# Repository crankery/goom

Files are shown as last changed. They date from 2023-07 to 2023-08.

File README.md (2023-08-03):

# Goom VCF

Goom is yet another Moog style transistor ladder VCF for Eurorack. It's setup to be a fairly shallow 14hp module.

This is mainly a re-layout of [Yves Usson's](http://yusynth.net/) [YuSynth MiniMoog VCF](http://yusynth.net/Modular/index_en.html). A few substitions of really super obsolete componetns with only somewhat obsolete components were made. Everything is through-hole mount, I haven't made the leap to SMT yet. There's similar designs using SMT devices out there; just search for "minimoog transistor ladder filter eurorack".

The original design was for a 5U modular synth because that's what Yves was building. You can still [buy the YuSynth PCB](https://www.soundtronics.co.uk/yusynth-diy-synth/) and adapt it to Eurorack power and figure out how to attach it to a front panel but it's really designed to be a MOTM module. 

This used three matched pairs of [BC547C NPN transistors](Documents/BC547.pdf), a [BC557C PNP transistor](Documents/BC557.pdf), a [TL072 op-amp](Documents/tl072h.pdf) and two [CA3046N transistor arrays](Documents/CA3046N.pdf). Of these components, the CA3056 and TL072 are still readily available. There's a clear substition for the transistors as well as a possible better option. The original design was for $\pm15V$; Yves suggests some resistor value changes for Eurorack's $\pm12V$ power. Matching transistors is still possible in this day and age but I felt like it was a pain so I decided to try out another option.

## Changes from YuSynth Design

You can still easily obtain BC5x7 transistors but I happened to have a bunch of 2N3904 and 2N3906 transistors on hand so I elected to use those. Then I decided trying to match pairs of them was a pain. Knowing the [Alfa RPAR AS394](https://www.alfarzpp.lv/eng/sc/AS394CH.pdf) matched transistor pair IC was available, I decided to try that out.
I've left the discrete transistor pads on the PCB.

The 2N3904 is standing in for the BC557, 2N3096 for the BC547N transistors.

Since the AS394 has internal diodes coming off the emitters, I've included pads for 2N4148 diodes on the optional discrete transistor pads. Again, 2N2148 was selected because I had them on hand.

## Design Constraints

The PCB is 100mm in the long dimension which makes it pretty darned cheap to order from [PCBWay](https://www.pcbway.com/). It is 70.8mm wide which [Doepfer says is 14hp](https://doepfer.de/a100_man/a100m_e.htm).

I elected to exclusively use through-hole components and PCB mount vertical potentiometers and jacks. Because some of these components are taller than the jacks and pots most of the components are on the opposite side of the PCB from the components that protrude from the front panel.

The potentiometers used are Alpha RD901F style 9mm vertical PCB mount with 6.35mm (1/4") round shafts and threaded collar to attach the front panel. The 10KΩ anti-log taper potentiometer was not available in this style so I used the RD901F which has a 6mm 18 tooth plastic shaft for resonance/emphasis. The jacks are PJ301BM 3.5mm switched tip mono jacks.

## Parts Sourcing

Most of the hardware and the discrete components were obtained from [Tayda](https://www.taydaelectronics.com/). The AS3046 & AS394 ICs are from [Cabintech](https://cabintechglobal.com/). The TL072 ICs were from either Mouser or Digi-key.

# Design

I started out by re-drawing the original design in [KiCad](https://www.kicad.org).

YuSynth Schematic

## To Do

- [ ] A note on the schematic `** resistor valus to be adjusted to adapt to input and output levels` which applies to R5 and R32. Not sure what the appropriate values are for Eurorack levels and this isn't discussed anywhere on the page
- [ ] The references are different in the KiCad schematic vs the original. Make them match
- [ ] The BOM says `47nF matched to 1%` for C4-7, not sure how to go about that

## Changes From Original

- R24, R27, R26 value changed for $\pm12V$
- Eliminated the MOTM power connection and switched all the $\pm15V$ to $\pm12V$
- Added a Eurorack 10 pin header power connector
- Switched the 3 x 100KΩ resistors to a 4 pin resistor network
- Switched the 4 x 470Ω resistors to an 8 pin isolated resistor pack 
- Added diodes off the matched transitor emitters as per the AS394's internals
- Added optional AS394 ICs to replace the matched transistors

# Front Panel

I'm trying to put the edge cuts for the panel, including jack and pot holes on a user layer. The graphics for the front panel are on another one.

## To Do

- [ ] determine how one goes about exporting a document to send to a service to get panels cut and drilled
- [ ] in the meantime, determine how to export the panel edge cuts layer to a pdf so the holes can be accurately drilled by hand in a blank panel
- [ ] determine how to go about exporting the graphics layer and doing some sort of acid etching process or something

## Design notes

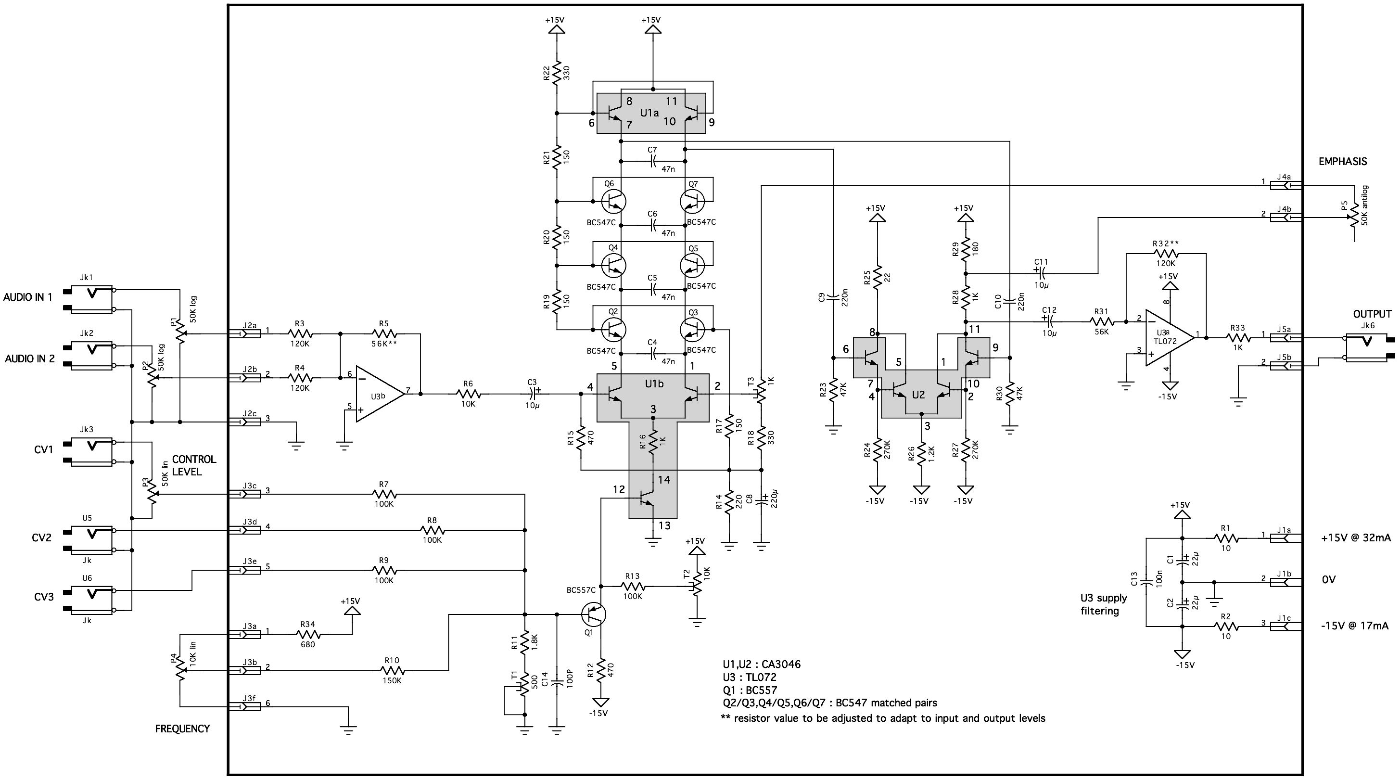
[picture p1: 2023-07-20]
Documents/Moogfilter-sch.jpg

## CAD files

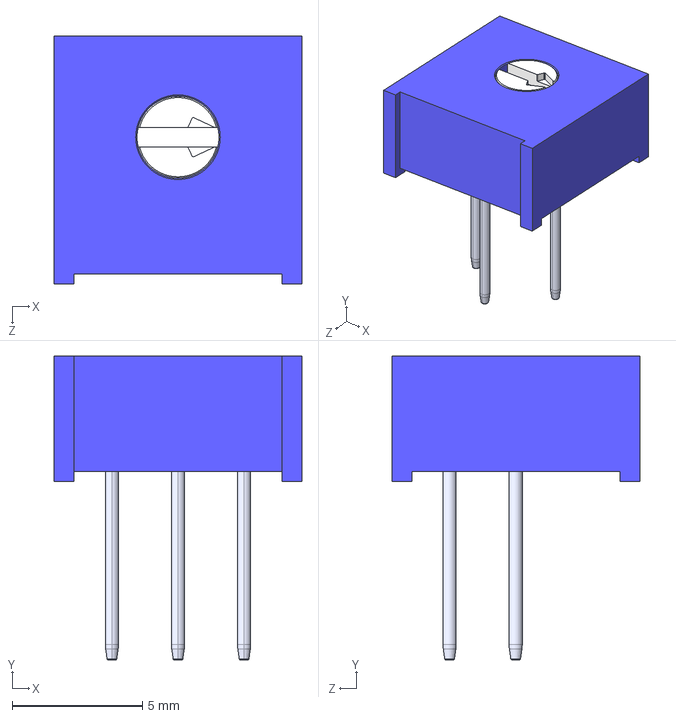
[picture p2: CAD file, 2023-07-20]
3dshapes/3386P-1-502LF.step
9.53 x 11.7 x 9.53 mm

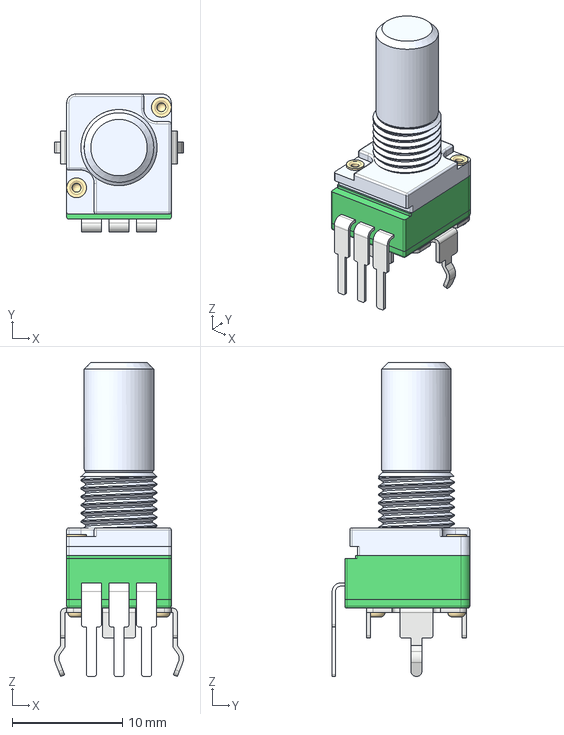
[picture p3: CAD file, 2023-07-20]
3dshapes/RD901F-40-15R1.stp
11.7 x 12.5 x 28.5 mm

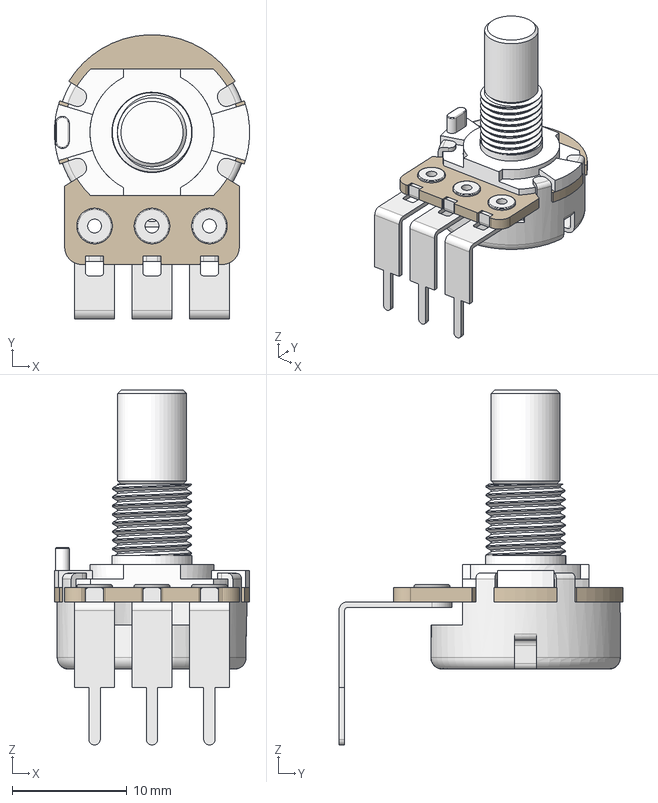
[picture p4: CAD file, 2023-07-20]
3dshapes/RV16AF-41.step
17.0 x 24.7 x 30.9 mm

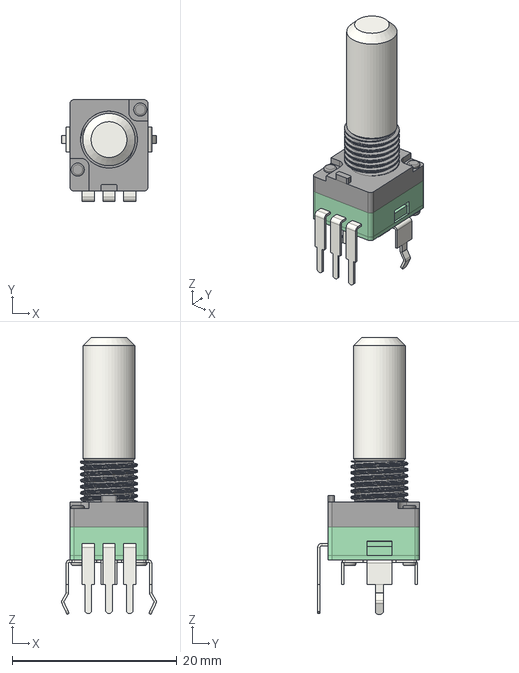
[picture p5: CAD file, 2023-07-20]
3dshapes/ALPHA-RD901F-40.step
11.5 x 12.4 x 33.6 mm

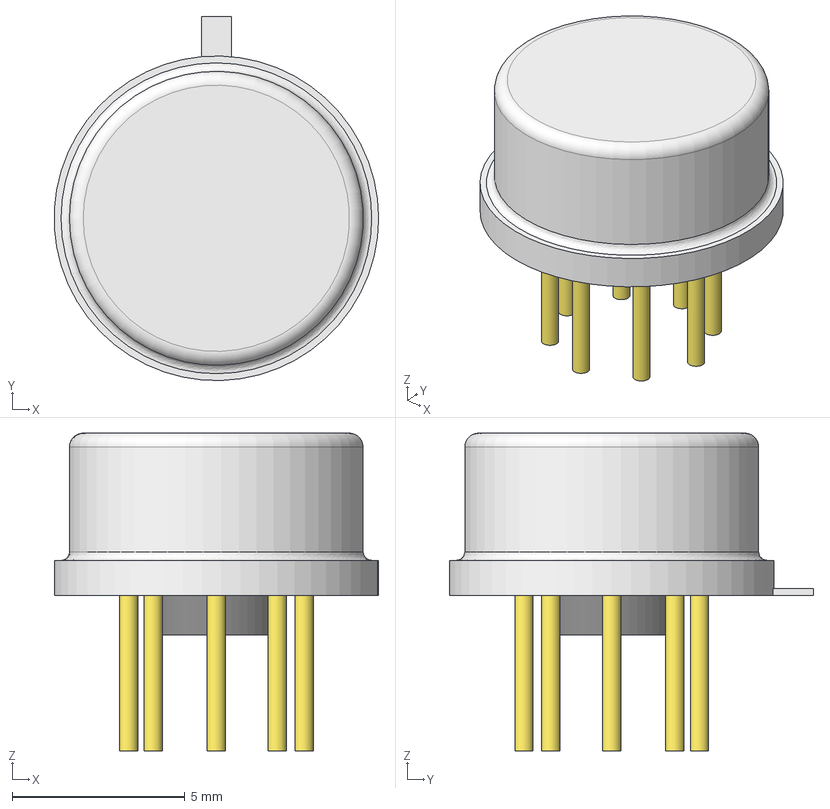
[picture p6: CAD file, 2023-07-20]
3dshapes/TO-5-8pins.step
9.39 x 10.5 x 9.20 mm
Sketch001

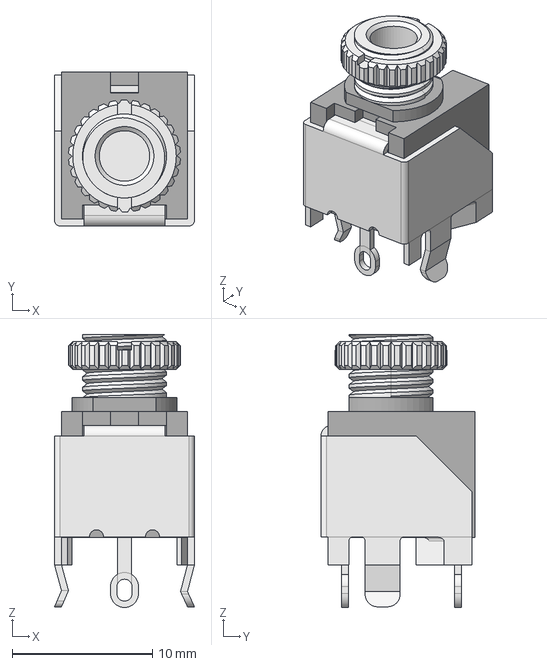
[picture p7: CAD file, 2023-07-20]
3dshapes/PJ301BM_Knurl_nut.step
10.0 x 11.0 x 19.5 mm

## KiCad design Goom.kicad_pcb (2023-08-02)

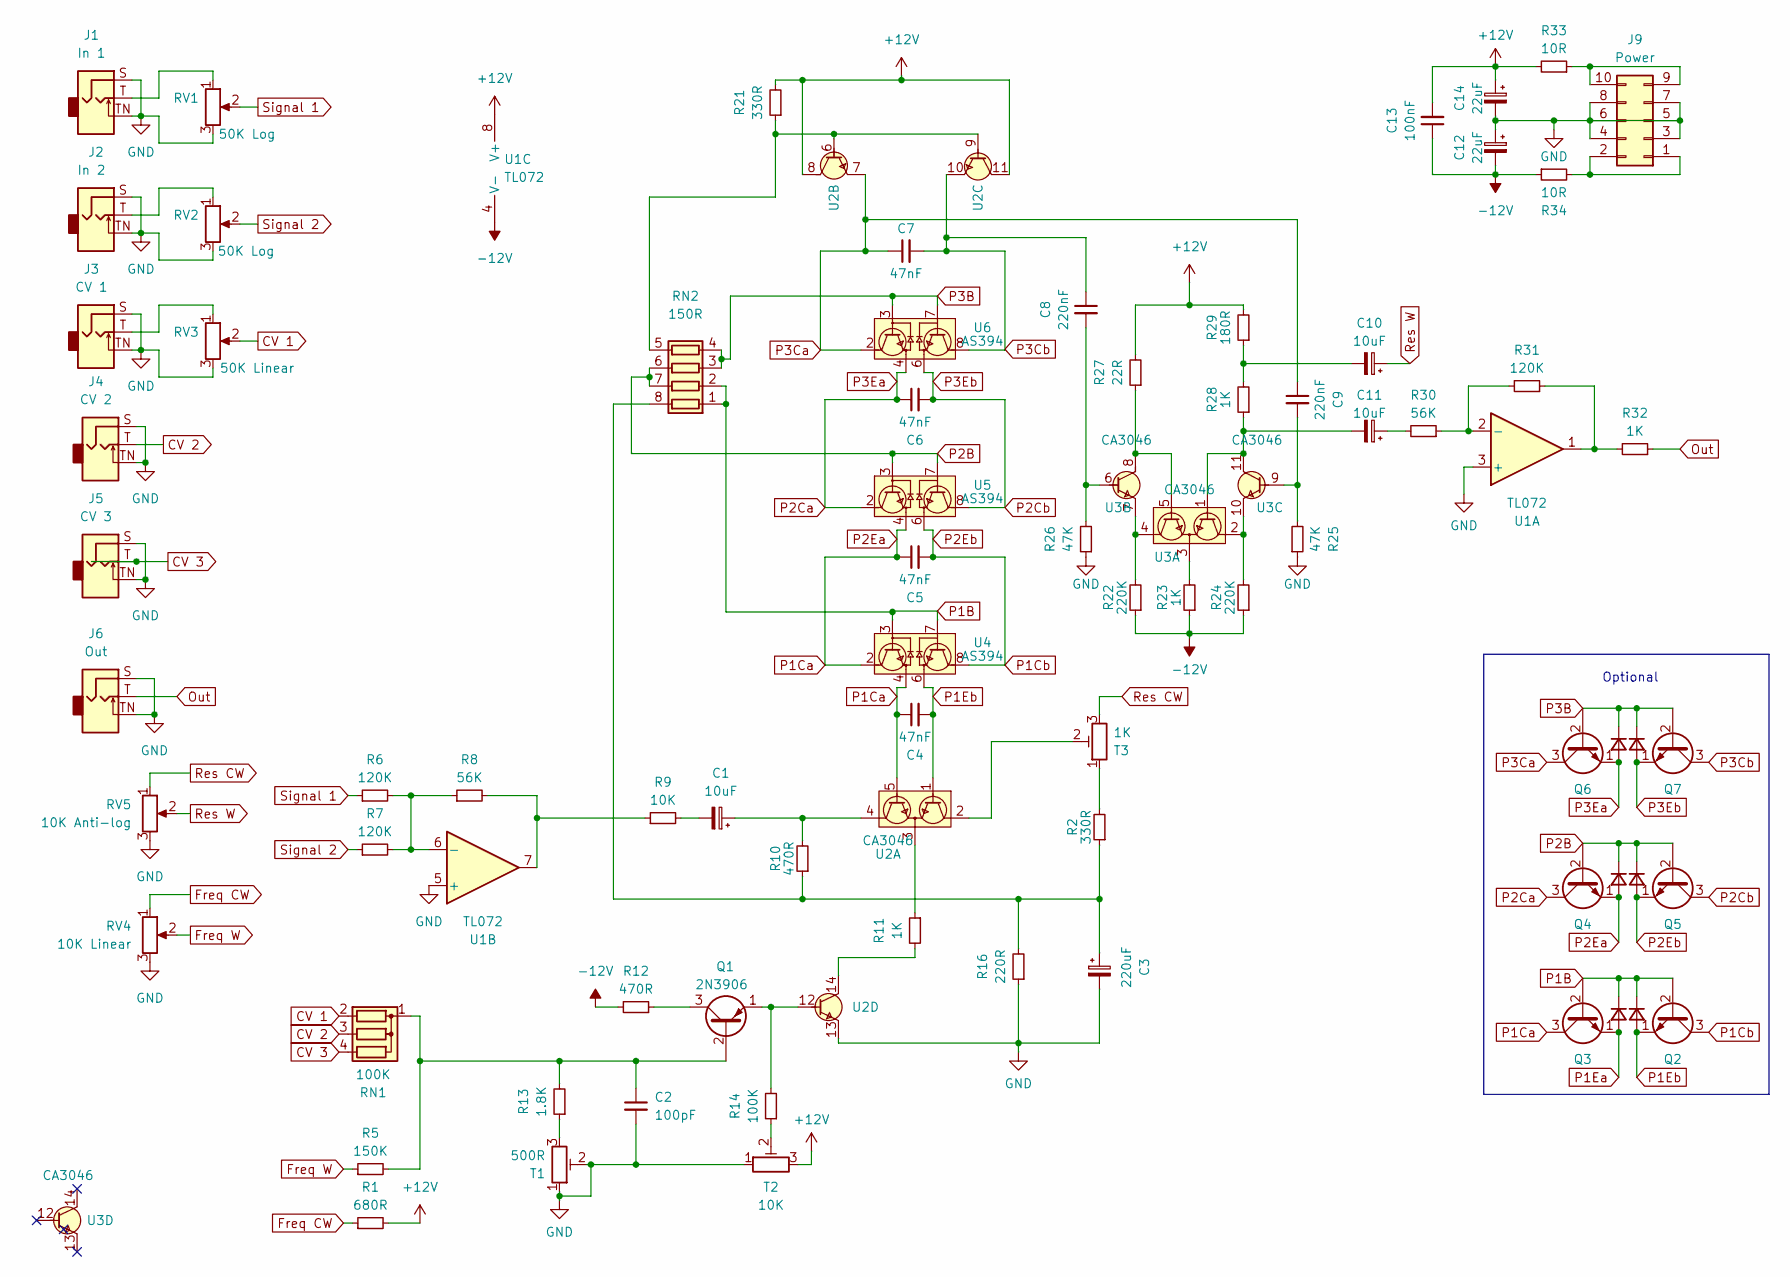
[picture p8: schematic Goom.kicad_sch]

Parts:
C1, C10, C11: 10uF; CP_Radial_D5.0mm_P2.50mm
C2: 100pF; C_Disc_D3.0mm_W2.0mm_P2.50mm
C3: 220uF; CP_Radial_D5.0mm_P2.50mm
C4, C5, C6, C7: 47nF; C_Rect_L7.2mm_W2.5mm_P5.00mm_FKS2_FKP2_MKS2_MKP2
C8, C9: 220nF; C_Rect_L7.2mm_W2.5mm_P5.00mm_FKS2_FKP2_MKS2_MKP2
C12, C14: 22uF; CP_Radial_D5.0mm_P2.50mm
C13: 100nF; C_Rect_L7.2mm_W2.5mm_P5.00mm_FKS2_FKP2_MKS2_MKP2
D1, D2, D3, D4, D5, D6: 2N4148; D_DO-35_SOD27_P7.62mm_Horizontal
J1: In 1; Jack_3.5mm_QingPu_WQP-PJ301BM_Vertical
J2: In 2; Jack_3.5mm_QingPu_WQP-PJ301BM_Vertical
J3: CV 1; Jack_3.5mm_QingPu_WQP-PJ301BM_Vertical
J4: CV 2; Jack_3.5mm_QingPu_WQP-PJ301BM_Vertical
J5: CV 3; Jack_3.5mm_QingPu_WQP-PJ301BM_Vertical
J6: Out; Jack_3.5mm_QingPu_WQP-PJ301BM_Vertical
J9: Power; IDC-Header_2x05_P2.54mm_Vertical
Q1: 2N3906; TO-92_Inline
Q2, Q3, Q4, Q5, Q6, Q7: 2N3904; TO-92_Inline
R1: 680R; R_Axial_DIN0204_L3.6mm_D1.6mm_P5.08mm_Horizontal
R2, R21: 330R; R_Axial_DIN0204_L3.6mm_D1.6mm_P5.08mm_Horizontal
R5: 150K; R_Axial_DIN0204_L3.6mm_D1.6mm_P5.08mm_Horizontal
R6, R7, R31: 120K; R_Axial_DIN0204_L3.6mm_D1.6mm_P5.08mm_Horizontal
R8, R30: 56K; R_Axial_DIN0204_L3.6mm_D1.6mm_P5.08mm_Horizontal
R9: 10K; R_Axial_DIN0204_L3.6mm_D1.6mm_P5.08mm_Horizontal
R10, R12: 470R; R_Axial_DIN0204_L3.6mm_D1.6mm_P5.08mm_Horizontal
R11, R23, R28, R32: 1K; R_Axial_DIN0204_L3.6mm_D1.6mm_P5.08mm_Horizontal
R13: 1.8K; R_Axial_DIN0204_L3.6mm_D1.6mm_P5.08mm_Horizontal
R14: 100K; R_Axial_DIN0204_L3.6mm_D1.6mm_P5.08mm_Horizontal
R16: 220R; R_Axial_DIN0204_L3.6mm_D1.6mm_P5.08mm_Horizontal
R22, R24: 220K; R_Axial_DIN0204_L3.6mm_D1.6mm_P5.08mm_Horizontal
R25, R26: 47K; R_Axial_DIN0204_L3.6mm_D1.6mm_P5.08mm_Horizontal
R27: 22R; R_Axial_DIN0204_L3.6mm_D1.6mm_P5.08mm_Horizontal
R29: 180R; R_Axial_DIN0204_L3.6mm_D1.6mm_P5.08mm_Horizontal
R33, R34: 10R; R_Axial_DIN0204_L3.6mm_D1.6mm_P5.08mm_Horizontal
RN1: 100K; R_Array_SIP4
RN2: 150R; R_Array_SIP8
RV1, RV2: 50K Log; Potentiometer_Alpha_RD901F-40-00D_Single_Vertical
RV3: 50K Linear; Potentiometer_Alpha_RD901F-40-00D_Single_Vertical
RV4: 10K Linear; Potentiometer_Alpha_RD901F-40-00D_Single_Vertical
RV5: 10K Anti-log; Potentiometer_Alpha_RD901F-40-00D_Single_Vertical
T1: 500R; Potentiometer_Bourns_3266Y_Vertical
T2: 10K; Potentiometer_Bourns_3386P_Vertical
T3: 1K; Potentiometer_Bourns_3386P_Vertical
U1: TL072; DIP-8_W7.62mm
U2, U3: CA3046; DIP-14_W7.62mm
U4, U5, U6: AS394; TO-5-8

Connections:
+12V: C13.2, C14.1, R1.2, R21.2, R27.2, R29.2, R33.2, T2.3, U1.8 (V+), U2.8 (Q3C), U2.11 (Q4C)
-12V: C12.2, C13.1, R12.2, R22.1, R23.1, R24.1, R34.1, U1.4 (V-)
CV 1: RN1.2 (R1), RV3.2
CV 2: J4.T, RN1.3 (R2)
CV 3: J5.T, RN1.4 (R3)
Freq CW: R1.1, RV4.1
Freq W: R5.1, RV4.2
GND: C2.2, C3.2, C12.1, C14.2, J1.S, J1.TN, J2.S, J2.TN, J3.S, J3.TN, J4.S, J4.TN, J5.S, J5.TN, J6.S, J6.TN, J9.3, J9.4, J9.5, J9.6, J9.7, J9.8, R16.1, R25.1, R26.1, RV1.3, RV2.3, RV3.3, RV4.3, RV5.3, T1.1, T1.2, T2.1, U1.3 (+), U1.5 (+), U2.13 (Q5E)
unnamed: C1.2, R9.2
unnamed: C10.2, R28.2, R29.1
unnamed: C11.1, R30.2
unnamed: J1.T, RV1.1
unnamed: J2.T, RV2.1
unnamed: J3.T, RV3.1
unnamed: J9.1, J9.2, R34.2
unnamed: J9.9, J9.10, R33.1
unnamed: C2.1, Q1.2 (B), R5.2, R13.2, RN1.1 (common)
unnamed: Q1.3 (C), R12.1
unnamed: Q1.1 (E), R14.2, U2.12 (Q5B)
unnamed: R2.2, T3.1
unnamed: R8.2, R9.1, U1.7
unnamed: R13.1, T1.3
unnamed: R14.1, T2.2
unnamed: R31.1, R32.2, U1.1
unnamed: C3.1, R2.1, R10.1, R16.2, RN2.8 (R1.2)
unnamed: R21.1, RN2.5 (R4.2), U2.6 (Q3B), U2.9 (Q4B)
unnamed: R30.1, R31.2, U1.2 (-)
unnamed: R6.2, R7.2, R8.1, U1.6 (-)
unnamed: T3.2, U2.2 (Q1B)
unnamed: R11.1, U2.3 (Q1/Q2E)
unnamed: C1.1, R10.2, U2.4 (Q2B)
unnamed: R11.2, U2.14 (Q5C)
unnamed: R24.2, U3.2 (Q1B), U3.10 (Q4E)
unnamed: C11.2, R28.1, U3.1 (Q1C), U3.11 (Q4C)
unnamed: R23.2, U3.3 (Q1/Q2E)
unnamed: R22.2, U3.4 (Q2B), U3.7 (Q3E)
unnamed: R27.1, U3.5 (Q2C), U3.8 (Q3C)
unnamed: C8.2, R26.2, U3.6 (Q3B)
unnamed: C9.2, R25.2, U3.9 (Q4B)
Out: J6.T, R32.1
P1B: D1.1 (K), D2.1 (K), Q2.2 (B), Q3.2 (B), RN2.1 (R1.1), RN2.2 (R2.1), U4.3 (Q1/Q2E), U4.7 (Q2B)
P1Ca: C4.1, C5.1, D3.2 (A), Q3.3 (C), Q4.1 (E), U2.5 (Q2C), U4.2 (Q1B), U4.4 (Q1C), U5.4 (Q1C)
P1Cb: C5.2, D4.2 (A), Q2.3 (C), Q5.1 (E), U4.8 (Q2B), U5.6 (Q1C)
P1Ea: D2.2 (A), Q3.1 (E)
P1Eb: C4.2, D1.2 (A), Q2.1 (E), U2.1 (Q1C), U4.6 (Q1C)
P2B: D3.1 (K), D4.1 (K), Q4.2 (B), Q5.2 (B), RN2.6 (R3.2), RN2.7 (R2.2), U5.3 (Q1/Q2E), U5.7 (Q2B)
P2Ca: C6.1, D5.2 (A), Q4.3 (C), Q6.1 (E), U5.2 (Q1B), U6.4 (Q1C)
P2Cb: C6.2, D6.2 (A), Q5.3 (C), Q7.1 (E), U5.8 (Q2B), U6.6 (Q1C)
P3B: D5.1 (K), D6.1 (K), Q6.2 (B), Q7.2 (B), RN2.3 (R3.1), RN2.4 (R4.1), U6.3 (Q1/Q2E), U6.7 (Q2B)
P3Ca: C7.1, C9.1, Q6.3 (C), U2.7 (Q3E), U6.2 (Q1B)
P3Cb: C7.2, C8.1, Q7.3 (C), U2.10 (Q4E), U6.8 (Q2B)
Res CW: RV5.1, T3.3
Res W: C10.1, RV5.2
Signal 1: R6.1, RV1.2
Signal 2: R7.1, RV2.2

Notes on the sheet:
Optional

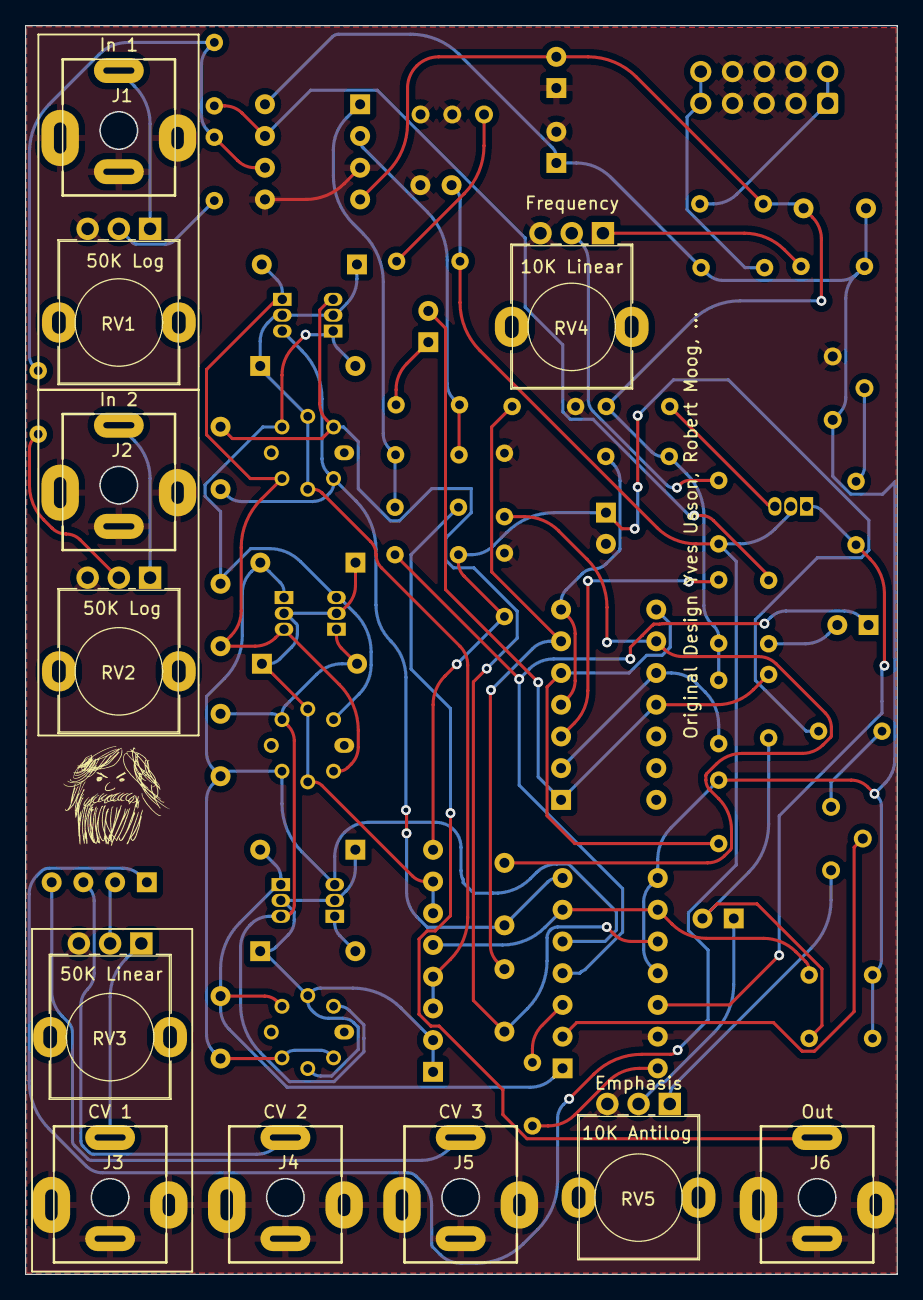
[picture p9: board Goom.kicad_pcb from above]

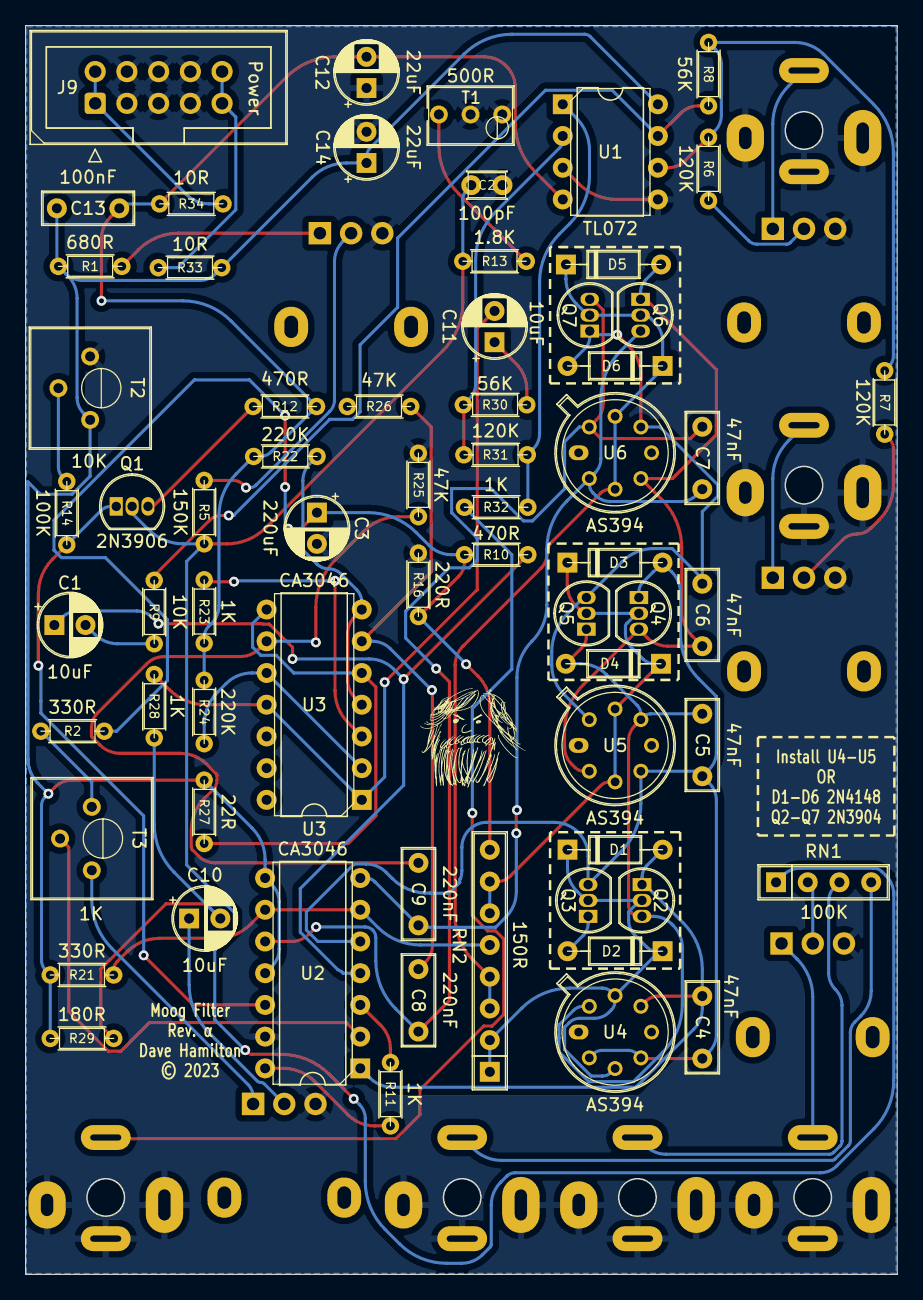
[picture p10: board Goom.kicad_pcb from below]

Board: 2 copper layers, 69.8 x 100.0 mm, 77 parts (66 on the bottom side), 55 nets.

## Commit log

2023-07-20 yeah, i should have done this a while ago
    [3386P-1-502LF.step, ALPHA-RD901F-40.step, Goom.kicad_pcb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]
2023-08-02 clean up
    [Goom.kicad_pcb]
2023-08-02 clean up again
    [Goom.kicad_pcb]
2023-08-02 add some gerbers
    [Goom-B_Cu.gbr, Goom-B_Mask.gbr, Goom-B_Paste.gbr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]

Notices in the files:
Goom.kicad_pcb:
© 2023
